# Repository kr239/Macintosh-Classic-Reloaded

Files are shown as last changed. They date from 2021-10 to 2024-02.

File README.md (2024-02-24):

# Macintosh-Classic-Reloaded

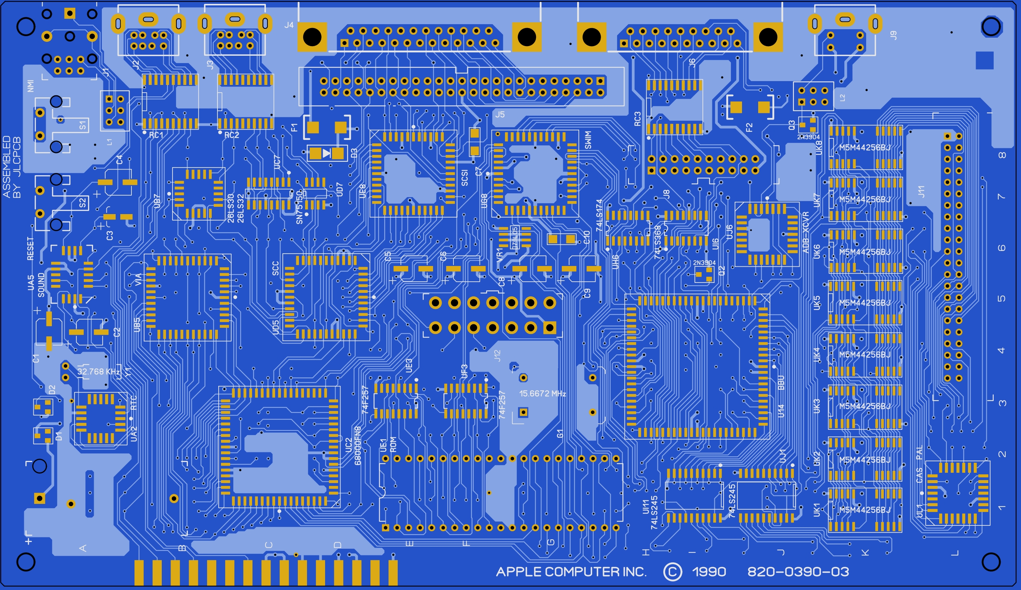
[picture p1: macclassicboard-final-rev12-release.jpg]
Finished Logic Board

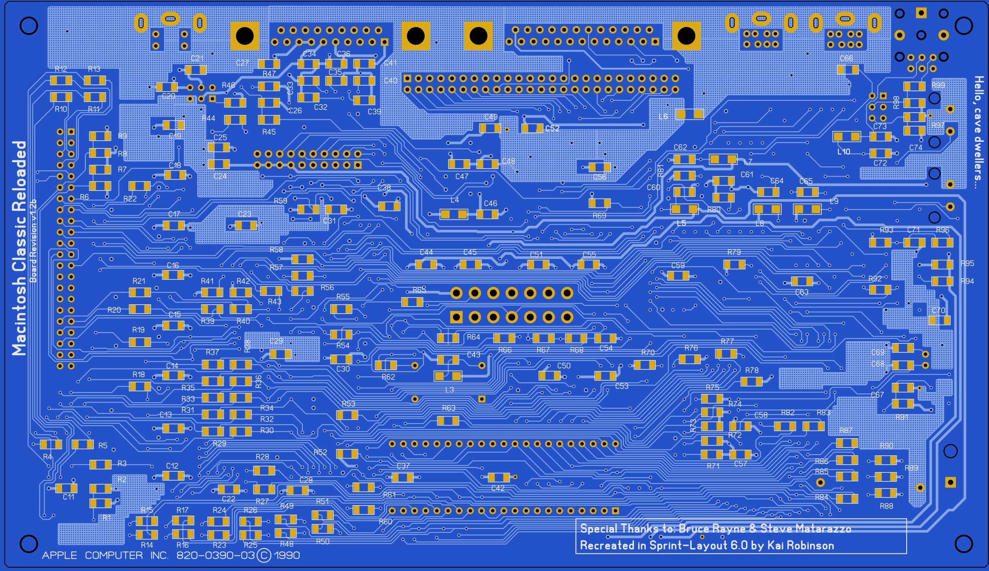
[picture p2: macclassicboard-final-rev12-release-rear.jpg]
Finished Logic Board - Bottom


A 1:1 Recreation of the Macintosh Classic logic board

As with the Macintosh SE, many Classic's have died because of Apple's short sighted decision to add a battery to the board - and unfortunately a particularly explosive one at that! This will inevitably pop and causes a horrific amount of damage.

Thankfully, because i've done this before, with the Macintosh SE, I decided to make a near 1:1 reproduction of the board, using Sprint Layout v6.0 again.

The Maxell batteries fitted to most classics, when they explode, will eat away at the component legs, tracks and via's if the battery electrolyte is left too long. Luckily almost all the other parts can be replaced with modern equivalents.

In the Macintosh Classic, the battery is placed in the bottom left hand corner of the board, underneath the RTC chip and to the left of the CPU. Mostly the damage is confined to this area, but if the system has been left a long time, you may discover the damage reaching beyond the SND chip (which is vital for generating the /RESET) functionality for the CPU and the board is essentially wrecked at this point.

Unlike the Macintosh SE, the PLCC versions of the SND and the RTC chip are not readily available and in the event of a total loss, will have to be salvaged from machines of a similar vintage.

The Macintosh II, IIx, IIfx, IIcx, IIci and IIsi all use the same SND and RTC chips - so if you have a destroyed/non-working board, you can salvage them from there.

As with the Macintosh SE board - there are other components than the custom chips that should be salvaged when possible, the 6-pin inductors/ferrite beads, the reset & programmers switch, RAMexpansion connector and headphone jack and try, if you can, to save the R/C network filters if possible, as these can be expensive to replace (sometimes £4 to £6 each!) Last but not least the DB-19 external Floppy connector, assuming the shell and pins haven't been eaten away by rust/battery electrolyte.

While it is possible to source some of the Apple custom IC's from resellers and chinese inventory warehouses, the supply cannot be guaranteed, so it is imperative that as many of the custom IC's are salvaged.

These boards aren't quite enough to build a new Macintosh Classic from scratch (maybe one day, though!) - so you'll need to harvest a few parts from your donor board.

* **RAM Expansion Socket** - 2 row, 44-pin connector - may be possible to substitute an IDC header.

* **DB19 Connector** - Almost NLA, only really available as NoS or Reclaimed. These are a bastard to get out cause the lugs are soldered. I found that pre-heating the joint first, filled with flux, then pressing hard into the pad with the desoldering gun, waiting til you see the solder go molten, you can often schlorp out the majority of the solder and then tidy up with wick afterwards.

  NoS ones available from https://www.exxoshost.co.uk/atari/store2/ - search for DB19F ASCI PCB RA POST

* **Main 14-pin Molex** - Molex P/N 39-28-1143 - Still available new - costs less than £2. Get a new one.

* **Inductors & Ferrite beads**

* **Passives** - REPLACE ALL - use high tolerance metal film resistors & Nichicon or Panasonic electrolytics.

* **AM26LS30's** - NLA, only available as NoS or Reclaimed

* **AM26LS32's** - Available new, but still worth reclaiming

* **MC3488A** - NLA - replace with Texas Instruments SN75150

* **Rockwell 338-6523** - This is the 65C22N VIA, still available new as the W65C22S6TPLG-14

* **RTC Chip** - Custom Chip - maybe possible to clone using a flex-PCB/ATTiny Chip

* **ADB Chip** - Apple branded PIC16CR54 in a PLCC package - maybe possible to re-produce/clone

* **BBU Chip** - Custom Chip - identical in pinout to the Macintosh SE

* **NCR5830/AM58C30 SCSI Chip** - Reclaim, but if not possible, these can be purchased from Mouser, as ZiLOG still makes them under the part number Z53C8003VSG

* **SWIM Floppy Chip** - Custom Chip - available NoS from UTSource

* **ROM Chip** - Toshiba TC534200 MASK ROM - Reclaim & reuse, but these are the same pinout as 27C040

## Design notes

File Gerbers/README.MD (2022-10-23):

Download and use the .zip archive for services such as PCBWay or JLCPCB.

Layer sequence is:

**MacintoshClassic_copper_top.gbr**

**MacintoshClassic_copper_inner1.gbr**

**MacintoshClassic_copper_inner2.gbr**

**MacintoshClassic_copper_bottom.gbr**

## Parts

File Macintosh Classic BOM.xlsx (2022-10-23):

Comment | Designator | Footprint | LCSC Part #（optional）
47uF | C1 | SMD,6.3x5.4mm | C442615
47uF | C2 | SMD,6.3x5.4mm | C442615
1uF | C3 | SMD,4x5.4mm | C445065
47uF | C4 | SMD,6.3x5.4mm | C442615
47uF | C5 | SMD,6.3x5.4mm | C442615
47uF | C6 | SMD,6.3x5.4mm | C442615
2.2uF | C7 | 1210 | C2324655
47uF | C8 | SMD,6.3x5.4mm | C442615
47uF | C9 | SMD,6.3x5.4mm | C442615
3.3uF | C10 | 1812 | C2174279
100nF | C11 | 1206 | C107181
100nF | C12 | 1206 | C107181
100nF | C13 | 1206 | C107181
100nF | C14 | 1206 | C107181
100nF | C15 | 1206 | C107181
100nF | C16 | 1206 | C107181
100nF | C17 | 1206 | C107181
100nF | C18 | 1206 | C107181
100nF | C19 | 1206 | C107181
560pF | C20 | 1206 | C415410
10nF | C21 | 1206 | C326648
10nF | C22 | 1206 | C326648
10nF | C23 | 1206 | C326648
10nF | C24 | 1206 | C326648
10nF | C25 | 1206 | C326648
680pF | C26 | 1206 | C437498
10nF | C27 | 1206 | C326648
10nF | C28 | 1206 | C326648
10nF | C29 | 1206 | C326648
10nF | C30 | 1206 | C326648
10nF | C31 | 1206 | C326648
560pF | C32 | 1206 | C415410
560pF | C33 | 1206 | C415410
10nF | C34 | 1206 | C326648
560pF | C35 | 1206 | C415410
10nF | C36 | 1206 | C326648
10nF | C37 | 1206 | C326648
10nF | C38 | 1206 | C326648
560pF | C39 | 1206 | C415410
560pF | C40 | 1206 | C415410
2.2nF | C41 | 1206 | C162456
10nF | C42 | 1206 | C326648
10nF | C43 | 1206 | C326648
100nF | C44 | 1206 | C107181
100nF | C45 | 1206 | C107181
10nF | C46 | 1206 | C326648
10nF | C47 | 1206 | C326648
10nF | C48 | 1206 | C326648
10nF | C49 | 1206 | C326648
10nF | C50 | 1206 | C326648
100nF | C51 | 1206 | C107181
10nF | C52 | 1206 | C326648
10nF | C53 | 1206 | C326648
68pF | C54 | 1206 | C141205
100nF | C55 | 1206 | C107181
100nF | C56 | 1206 | C107181
10nF | C57 | 1206 | C326648
10nF | C58 | 1206 | C326648
10nF | C59 | 1206 | C326648
10nF | C60 | 1206 | C326648
10nF | C61 | 1206 | C326648
10nF | C62 | 1206 | C326648
10nF | C63 | 1206 | C326648
10nF | C64 | 1206 | C326648
10nF | C65 | 1206 | C326648
560pF | C66 | 1206 | C415410
100nF | C67 | 1206 | C107181
33pF | C68 | 1206 | C85570
10pF | C69 | 1206 | C107172
100nF | C70 | 1206 | C107181
100nF | C71 | 1206 | C107181
100nF | C72 | 1206 | C107181
1nF | C73 | 1206 | C23631
1nF | C74 | 1206 | C23631
4.7kΩ | R1 | 1206 | C242482
22Ω | R3 | 1206 | C205216
22Ω | R4 | 1206 | C205216
22Ω | R5 | 1206 | C205216
10kΩ | R7 | 1206 | C205047
10kΩ | R8 | 1206 | C205047
22Ω | R10 | 1206 | C205216
22Ω | R11 | 1206 | C205216
22Ω | R12 | 1206 | C205216
22Ω | R13 | 1206 | C205216
22Ω | R14 | 1206 | C205216
22Ω | R15 | 1206 | C205216
22Ω | R16 | 1206 | C205216
22Ω | R17 | 1206 | C205216
22Ω | R18 | 1206 | C205216
22Ω | R19 | 1206 | C205216
22Ω | R20 | 1206 | C205216
22Ω | R21 | 1206 | C205216
22Ω | R22 | 1206 | C205216
22Ω | R23 | 1206 | C205216
22Ω | R24 | 1206 | C205216
22Ω | R25 | 1206 | C205216
22Ω | R26 | 1206 | C205216
22Ω | R27 | 1206 | C205216
22Ω | R28 | 1206 | C205216
22Ω | R29 | 1206 | C205216
22Ω | R30 | 1206 | C205216
22Ω | R31 | 1206 | C205216
22Ω | R32 | 1206 | C205216
22Ω | R33 | 1206 | C205216
22Ω | R34 | 1206 | C205216
22Ω | R35 | 1206 | C205216
22Ω | R36 | 1206 | C205216
22Ω | R37 | 1206 | C205216
22Ω | R38 | 1206 | C205216
22Ω | R39 | 1206 | C205216
22Ω | R40 | 1206 | C205216
10kΩ | R41 | 1206 | C205047
470Ω | R42 | 1206 | C114945
22Ω | R43 | 1206 | C205216
1kΩ | R44 | 1206 | C131398
22Ω | R45 | 1206 | C205216
470Ω | R46 | 1206 | C114945
3.3kΩ | R47 | 1206 | C137292
22Ω | R48 | 1206 | C205216
22Ω | R49 | 1206 | C205216
22Ω | R50 | 1206 | C205216
22Ω | R51 | 1206 | C205216
4.7kΩ | R52 | 1206 | C242482
22Ω | R53 | 1206 | C205216
47Ω | R54 | 1206 | C17969
22Ω | R55 | 1206 | C205216
22Ω | R56 | 1206 | C205216
10kΩ | R57 | 1206 | C205047
10kΩ | R58 | 1206 | C205047
10kΩ | R59 | 1206 | C205047
22Ω | R60 | 1206 | C205216
22Ω | R61 | 1206 | C205216
47Ω | R62 | 1206 | C17969
22Ω | R63 | 1206 | C205216
47Ω | R64 | 1206 | C17969
47Ω | R65 | 1206 | C17969
47Ω | R66 | 1206 | C17969
1.2kΩ | R67 | 1206 | C185265
47Ω | R68 | 1206 | C17969
10kΩ | R69 | 1206 | C205047
4.7kΩ | R70 | 1206 | C242482
10kΩ | R71 | 1206 | C205047
10kΩ | R72 | 1206 | C205047
1kΩ | R73 | 1206 | C131398
4.7kΩ | R74 | 1206 | C242482
4.7kΩ | R75 | 1206 | C242482
4.7kΩ | R76 | 1206 | C242482
22Ω | R77 | 1206 | C205216
4.7kΩ | R78 | 1206 | C242482
330Ω | R79 | 1206 | C114944
3.3kΩ | R80 | 1206 | C137292
10kΩ | R81 | 1206 | C205047
22Ω | R82 | 1206 | C205216
22Ω | R83 | 1206 | C205216
22Ω | R84 | 1206 | C205216
22Ω | R85 | 1206 | C205216
22Ω | R86 | 1206 | C205216
22Ω | R87 | 1206 | C205216
100kΩ | R88 | 1206 | C137393
100kΩ | R89 | 1206 | C137393
100kΩ | R90 | 1206 | C137393
1kΩ | R91 | 1206 | C131398
100Ω | R92 | 1206 | C113307
47Ω | R93 | 1206 | C17969
560kΩ | R94 | 1206 | C205087
10Ω | R95 | 1206 | C17903
47Ω | R96 | 1206 | C17969
10Ω | R97 | 1206 | C17903
22Ω | R98 | 1206 | C205216
100Ω | R99 | 1206 | C113307
FB | L3 | 1206 | C16902
FB | L4 | 1206 | C16902
FB | L5 | 1206 | C16902
FB | L6 | 1206 | C16902
FB | L7 | 1206 | C16902
FB | L8 | 1206 | C16902
FB | L9 | 1206 | C16902
FB | L10 | 1206 | C16902
MMBD914 | D1 | 1206 | C156345
MMBD914 | D2 | 1206 | C156345
2N3904 | Q2 | SOT-23 | C84555
2N3904 | Q3 | SOT-23 | C84555
SN75150 | UD7 | SOIC-8 | C2868946
74F257 | UE3 | SO-16
74F257 | UF3 | SO-16
74LS174 | UH6 | SOIC-16 | C7744
74HCT368 | UI6 | SOIC-16
74LS245 | UI1 | SOIC-20
74LS245 | UJ1 | SOIC-20
79L05 | VR1 | SOIC-8

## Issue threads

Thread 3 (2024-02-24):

Trace spacing less than 0.1mm

KINEX605, 2024-02-24:
Hello,

I wanted to have this PCB produced by PCBway using the MacintoshClassicGerbers-v1.2d-FINAL.zip file, but their audit returned an issue with at least one trace having less than 0.1mm spacing.

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

kr239, 2024-02-24:
Can you zoom out - that looks like a PLCC pad, but i'm unable to see where that issue is.

KINEX605, 2024-02-24:
That is all of the information that PCBWay provided. Based on my inspection of the design in the viewer, I believe the trace in question is for one of the M5M44256BJ chips.

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

kr239, 2024-02-24:
Great - thanks for that - I've just made some trace adjustments - new gerbers inbound! :)

Closed 2024-02-24.

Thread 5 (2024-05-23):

Incorrect resistor part number for R94

KINEX605, 2024-05-23:
I had built up the board successfully but I had no startup bong and only quiet sound when the volume was raised to the maximum level. This [post on the tinkerdifferent.com forums](https://tinkerdifferent.com/threads/logic-board-macintosh-classic-reloaded.26/post-21105) also indicated the same issue but the user later fixed it and said that they made an error in a resistor value.

I have confirmed that [Macintosh Classic BOM.xlsx](https://github.com/kr239/Macintosh-Classic-Reloaded/blob/main/Macintosh%20Classic%20BOM.xlsx) indicates to use [LCSC part number C205087](https://www.lcsc.com/product-detail/Chip-Resistor-Surface-Mount_BOURNS-CR1206-FX-5600ELF_C205087.html) but that is for a 560Ω resistor and not for a 560kΩ one.

Once the R94 resistor was replaced on the logic board for a 560kΩ one, sound functioned as expected.

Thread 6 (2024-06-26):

R66, C75 or both?

federicopitto, 2024-06-26:
Hello. I'm slowly working my way moving the smd components from the back of the board of the old one to the new one.
In my original board (marked 820-0390-B 630-0390-A) I do have C75 instead of R66 connected to the HS signal.
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

The Bomark schematics has both components
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

Do you have any suggestion here about what component is better to install, the resistor, the capacitor or both?

Keep up the good work

federicopitto, 2024-06-27:
EDIT: I did find R66 on its way to pin 60 of the B.B.U. On my board it is placed in-between R54 and C30.

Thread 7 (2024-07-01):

Possible broken connection between pin 12 an GND on the SCSI chip footprint

federicopitto, 2024-07-01:
Hello Kai. I hope you will read this.
I assemble the board and the Mac sprang back to life except for the SCSI interface. All diagnostics reported the SCSI bus as not connected. I traced back all the connections on the SCSI chip and I found the pin 12 was floating and not connected to GND, while the other grounded pins 3, 31, 36 and 42 were all correctly connected.
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

I tried looking at your sprint layout and I think I found a gap in the connection between pin 16 and the large flooded area under the chip connecting directly pin 16 to 31 and to the vias.
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

I'm quite positive I did not damage the board while soldering and my solder joints definitely look ok, maybe given the tolerances on the manufacturing process it is an issue that may happen or not.  Anyway, I soldered a resistor leg directly from pin 16 to 31 and the SCSI bus immediatly woke up and booted from the original hdd.
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

I will not desolder the chip so I cannot be completely sure about the state of the pad connection, but I thought I would let you know.

Keep up the good work!

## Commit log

2024-02-24 Add files via upload
    v1.2d FINAL
    * Edited traces around INT SCSI header for better clearance.
2024-02-24 Delete Gerbers/MacintoshClassicGerbers-v1.2c-FINAL.zip
    Replacing with new version.
2024-02-24 Delete Gerbers/MacintoshClassicGerbers-v1.2d-FINAL.zip
    Re-worked for v1.2e.
2024-02-24 Add files via upload
    v1.2e - made trace changes on RAM side for better clearance.
    [MacintoshClassic_copper_top.gbr, MacintoshClassic_silkscreen_bottom.gbr]
